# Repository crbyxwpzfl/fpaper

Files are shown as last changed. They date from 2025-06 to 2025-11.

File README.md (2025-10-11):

#### https://github.com/Elecrow-RD/CrowPanel-ESP32-4.2-E-paper-HMI-Display-with-400-300 - original files/docs
#### https://github.com/javl/image2cpp - the dithering is so cool javl
#### https://www.autodesk.com/community/gallery/project/132949/sg90-9g-micro-servo - nice servo modell of ccirone2
#### rest - is ai and me

todo - advanced perhpas stupid - store pointers to responsive peers in a vector of pointers to peer structs. on start up load complete peers blob into second allpeers vector with actual contigous structs holding the data. then on first connection put pointers to responsive peers into this first vector. then once one peer goes offline or comes back just update the pointer vector. for recieving a message this reduces the amount of hkdfs to try and no check for offline bool would be neccessary. but this uses uint32 pointer instead of just bool perhps this overhead is ok perhapsthis is even better than haveing the bool in a struct since alingmnet and wasted bufferbytes. 

todo - test thread safety thoroughly esp. revise onTopic callback

todo - curretnly 200KB ram is free this is not too much consider moving stuff to PSRAM

todo - perhpas reduce app partion to 1MB and increase nvs space to 4MB to allow more foto space

todo - add ram info and revise prefernces like rotation,btn pin, add show anything cmd,

todo - silence epd and mqtt lib

todo - revise boot sequence first sohw boot screen perhaps even progressbar (partial refresshs) also only start mqtt task when wifi connected ans so on

vision - do not hardcode firmware link istead querry latest release and compare to current version

vision - this perhaps is stoopid but somehow encrypt hkdfs until used so a leak/dump is not catastrophic

vision - replace prefs. reads and puts with perhpas rtos message buffers for thread safety

vision - forward secrecy and somthing like diffi hellman/newhope/kyber

vision - use encryption of nvs

vision - auto recover from connection loss

this is the current custom partition no spiffs!! also always set app0 at 0x10000 otherwise merged.bin is broken
```
| Name     | Type  | SubType  | Offset   | Size     | Size (MB)   |
|----------|-------|----------|----------|----------|-------------|
| otadata  | data  | ota      | 0x9000   | 0x2000   | 0.00781 MB  |
| app0     | app   | ota_0    | 0x10000  | 0x200000 | 2.00000 MB  |
| app1     | app   | ota_1    | 0x210000 | 0x200000 | 2.00000 MB  |
| coredump | data  | coredump | 0x410000 | 0x10000  | 0.06250 MB  |
| nvs      | data  | nvs      | 0x420000 | 0x200000 | 2.00000 MB  |

-- total ~6.07/8 MB (~1.93 MB free)
```

previously we had minispiffs
```
Label       Offset     Size (hex)   Size (bytes)    Size (KB)   Size (MB)
nvs         0x009000   0x005000     20,480          20.0        0.0195
otadata     0x00E000   0x002000     8,192           8.0	        0.0078
app0        0x010000   0x1E0000     1,966,080       1,920.0     1.875
app1        0x1F0000   0x1E0000     1,966,080       1,920.0     1.875
spiffs      0x3D0000   0x020000     131,072         128.0       0.125
coredump    0x3F0000   0x010000     65,536          64.0        0.0625

Region          Start       End         Size (bytes)    Size (MB)
Bootloader      0x0000      0x8000      32,768          0.03125
Partition Table 0x8000      0x9000      4,096           0.0039
All partitions  0x9000      0x400000    4,142,848       ~3.95
Unused          0x400000    0x800000    4,194,304       4.0
```

install arduino cli
```
curl -fsSL https://raw.githubusercontent.com/arduino/arduino-cli/master/install.sh | BINDIR=/home/codespace/.local/bin sh
```

allow lib form git links
```
export ARDUINO_LIBRARY_ENABLE_UNSAFE_INSTALL=true
```

init arduino sketch
```
arduino-cli sketch new "test"
```

update core index
```
arduino-cli core update-index  --additional-urls "https://espressif.github.io/arduino-esp32/package_esp32_index.json"
```

find core paltform
```
arduino-cli board search esp32
```

install core platform 
```
arduino-cli core install esp32:esp32
```

find board fqbn
```
arduino-cli board search ESP32S3 Dev Module
```

check board
```
arduino-cli board details -b esp32:esp32:esp32s3:PartitionScheme=custom,PSRAM=opi,FlashMode=qio,FlashSize=8M
```

compile with
```
arduino-cli compile -v --fqbn esp32:esp32:esp32s3:PartitionScheme=custom,PSRAM=opi,FlashMode=qio,FlashSize=8M --build-path ./firmware
```

/home/codespace/.arduino15/packages/esp32/hardware/esp32/3.2.0/tools/partitions

arduino-cli compile -v --fqbn esp32:esp32:esp32s3:PartitionScheme=custom,CustomPartitions=partitions,PSRAM=opi,FlashMode=qio,FlashSize=8M --build-path ./firmware

cp /workspaces/fpaper/test/partitions.csv /home/codespace/.arduino15/packages/esp32/hardware/esp32/3.2.0/tools/partitions/custom.csv

'merged.bin' at adress 0x0 with https://espressif.github.io/esptool-js/ for web programming

/home/codespace/.arduino15/packages/esp32/tools/esptool_py/4.9.dev3/esptool --chip esp32s3 partition_table --partition-table-file partitions.csv

esptool.py --chip esp32s3 merge_bin -o merged.bin --flash_mode qio --flash_freq 80m --flash_size 8MB \
  0x0 firmware/test.ino.bootloader.bin \
  0x8000 firmware/test.ino.partitions.bin \
  0x9000 nvs_data.bin \
  0x210000 firmware/test.ino.bin

/home/codespace/.arduino15/packages/esp32/tools/esptool_py/4.9.dev3/esptool --chip esp32s3 merge_bin -o merged-manual.bin --flash_mode qio --flash_freq 80m --flash_size 8MB \
  0x0 firmware/test.ino.bootloader.bin \
  0x8000 firmware/test.ino.partitions.bin \
  0x210000 firmware/test.ino.bin

psram view - 
```
void setup() {
  Serial.begin(115200);

  if (psramFound()) {
    Serial.println("PSRAM is found!");

    Serial.print("Total PSRAM: ");
    Serial.println(ESP.getPsramSize());

    Serial.print("Free PSRAM: ");
    Serial.println(ESP.getFreePsram());
  } else {
    Serial.println("No PSRAM available.");
  }
}
```

ram view - 
```
void setup() {
  Serial.begin(115200);
  
  // Total heap available
  Serial.print("Total heap: ");
  Serial.println(ESP.getHeapSize());

  // Free heap
  Serial.print("Free heap: ");
  Serial.println(ESP.getFreeHeap());

  // Minimum ever free heap (worst case)
  Serial.print("Minimum free heap: ");
  Serial.println(ESP.getMinFreeHeap());

  // Largest contiguous block that can be allocated (optional)
  Serial.print("Max allocatable block: ");
  Serial.println(heap_caps_get_largest_free_block(MALLOC_CAP_8BIT));
}
```

esp webrtc anywhere -https://www.reddit.com/r/esp32/comments/atnl6r/esp32_anywhere_access_webrtc_stun_turn_ice/

public mwtt broker - https://www.emqx.com/en/blog/popular-online-public-mqtt-brokers
emqx seems yo silently drop large messages hive does not

esp webrtc plus bootstrap - https://www.hackster.io/donowak/esp32-web-server-using-bootstrap-4-and-websockets-0bf950

esp webrtc stream - https://github.com/sepfy/libpeer/tree/main/examples/esp32

esp husarnet tailnetlike - https://medium.com/husarion-blog/lan-network-for-microcontrollers-over-the-internet-fbcfe4c97f4b

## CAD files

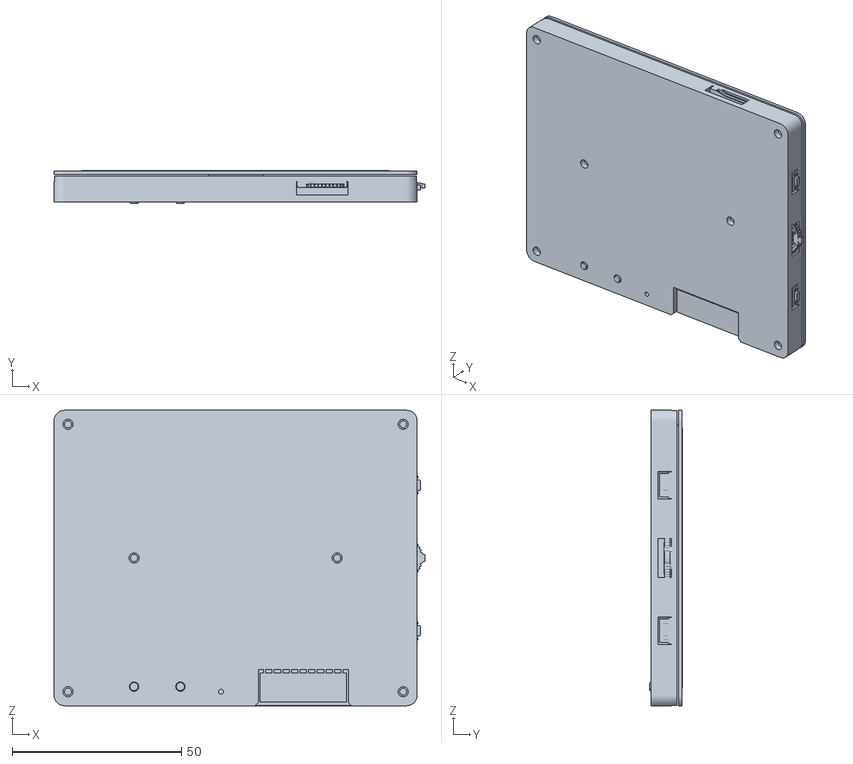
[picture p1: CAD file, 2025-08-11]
fusion files/original full assembly.stl
109.6 x 9.80 x 87.3

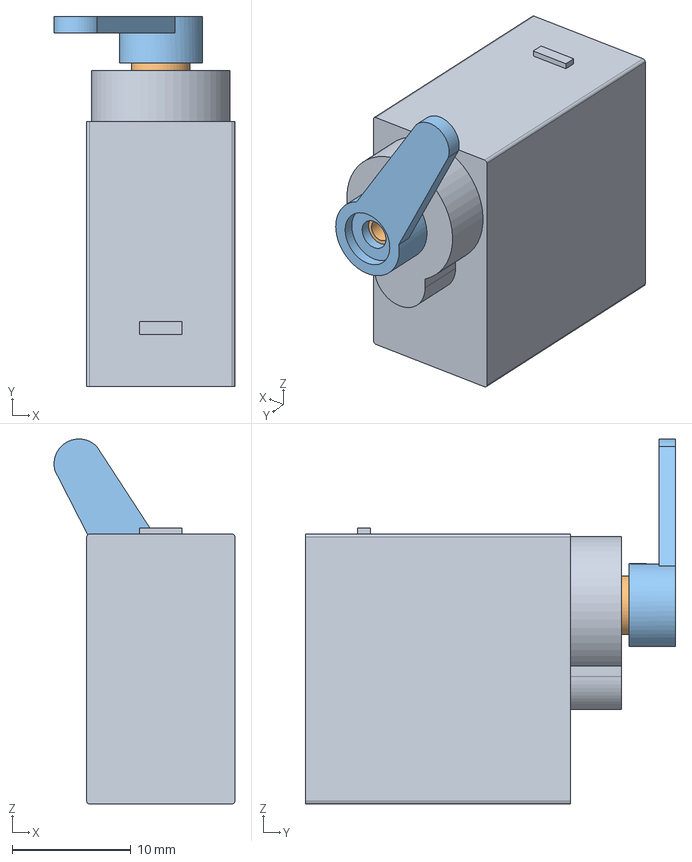
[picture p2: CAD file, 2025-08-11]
fusion files/fp servo v4.step
15.3 x 31.2 x 30.8 mm
servo_1
splined-drive
horn

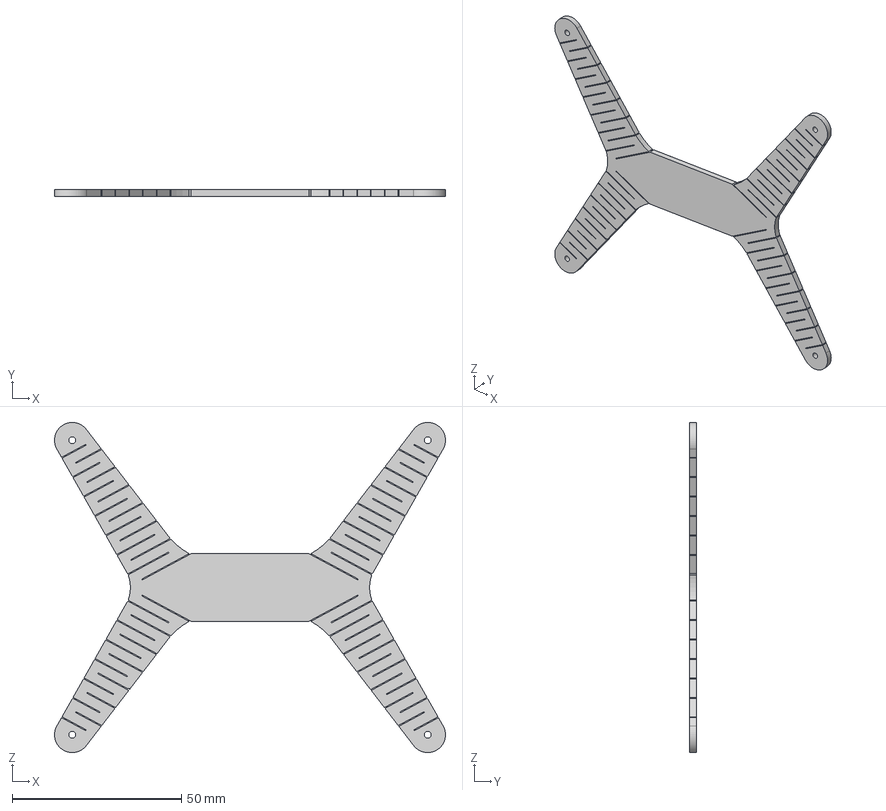
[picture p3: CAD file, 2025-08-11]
fusion files/fp flexplate v15.step
115.5 x 2.00 x 97.5 mm
Komponente1
Komponente7

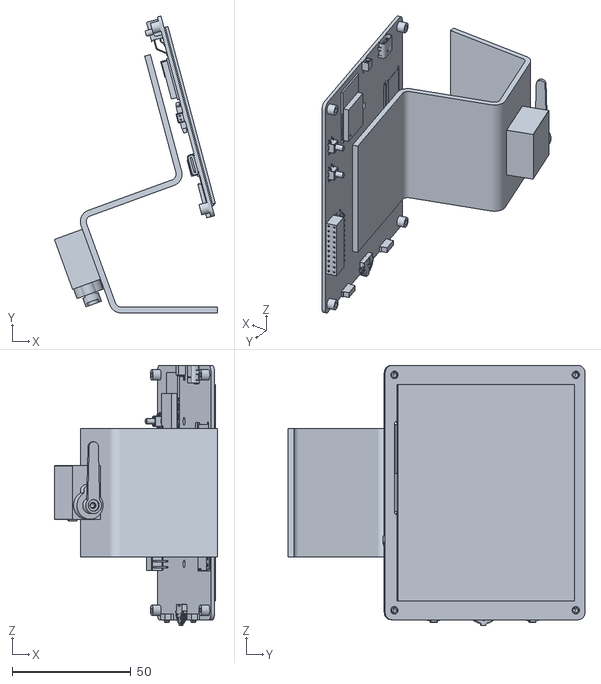
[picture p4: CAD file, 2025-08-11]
fusion files/fp mac like v2.stl
68.7 x 124.9 x 109.4

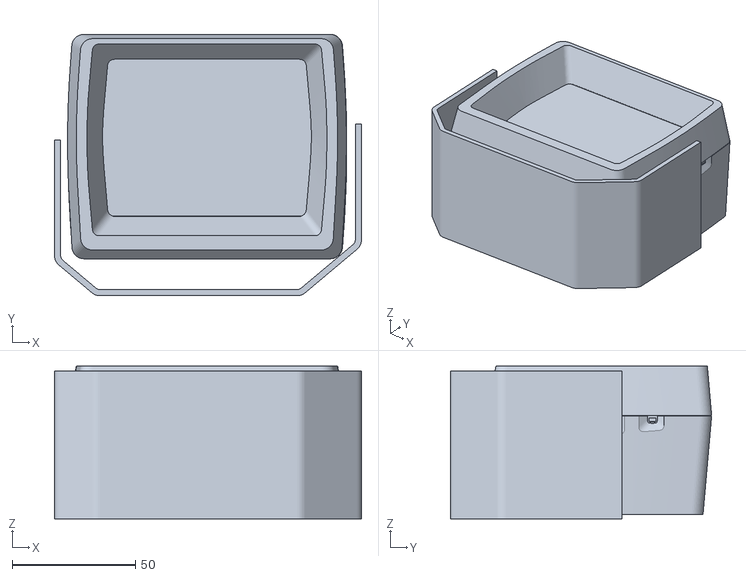
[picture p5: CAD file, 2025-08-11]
fusion files/fp severence v4.stl
124.5 x 105.9 x 62.0

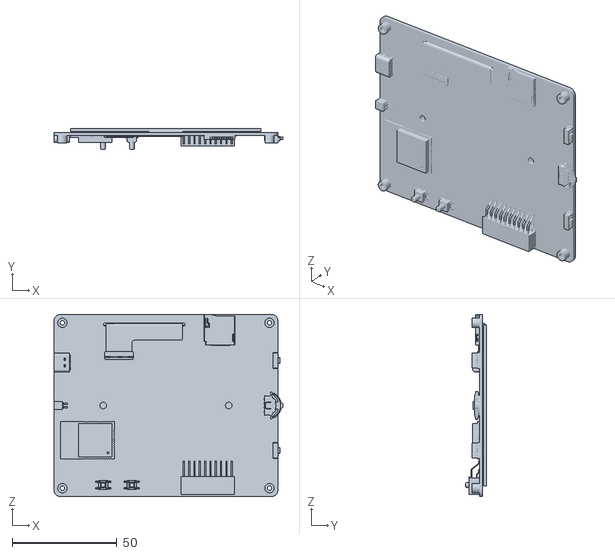
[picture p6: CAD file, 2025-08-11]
fusion files/original panel + pcb.stl
109.4 x 9.80 x 87.0

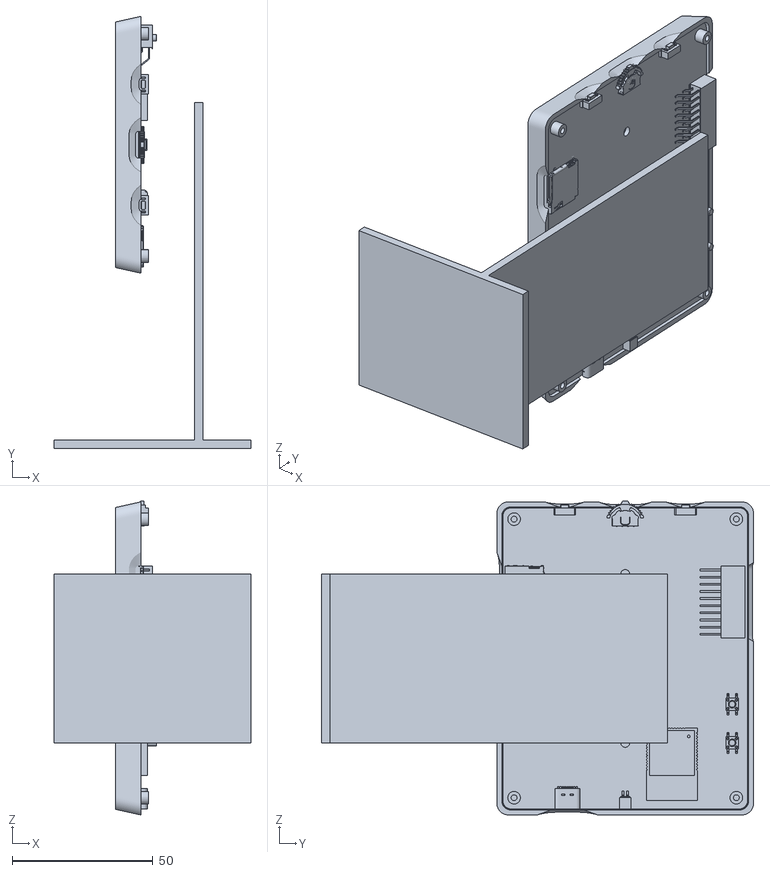
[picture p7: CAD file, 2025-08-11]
fusion files/fp simplestand v13.stl
70.0 x 153.7 x 111.6

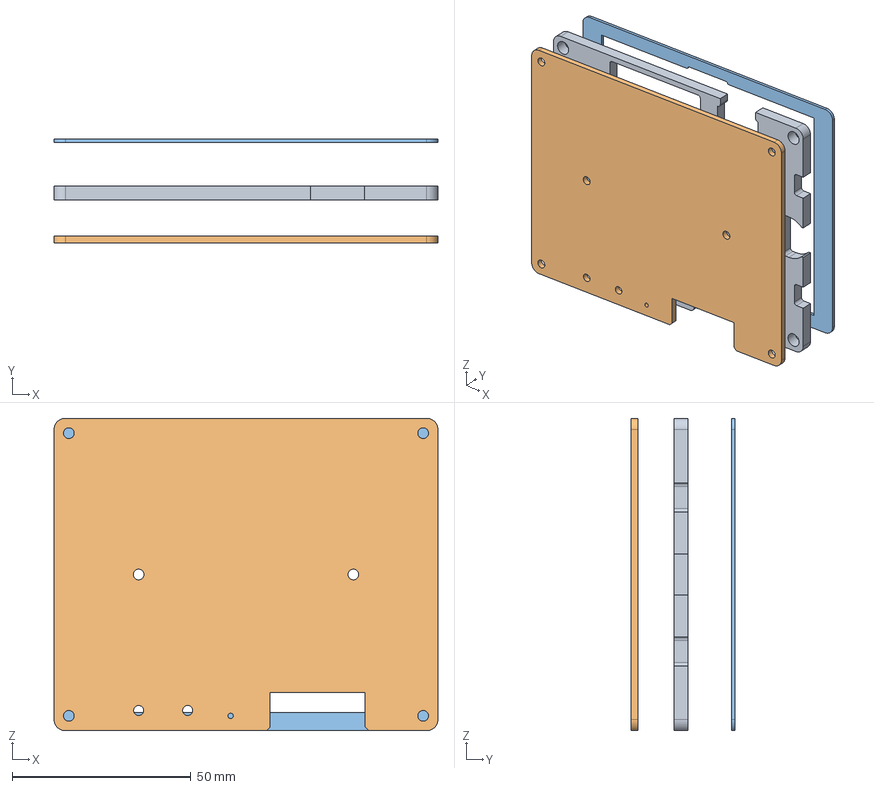
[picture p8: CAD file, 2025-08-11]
fusion files/original plates.step
107.3 x 29.1 x 87.3 mm
42-MIDDLE-COVER
42-BOTTOM-COVER
42-TOP_COVER

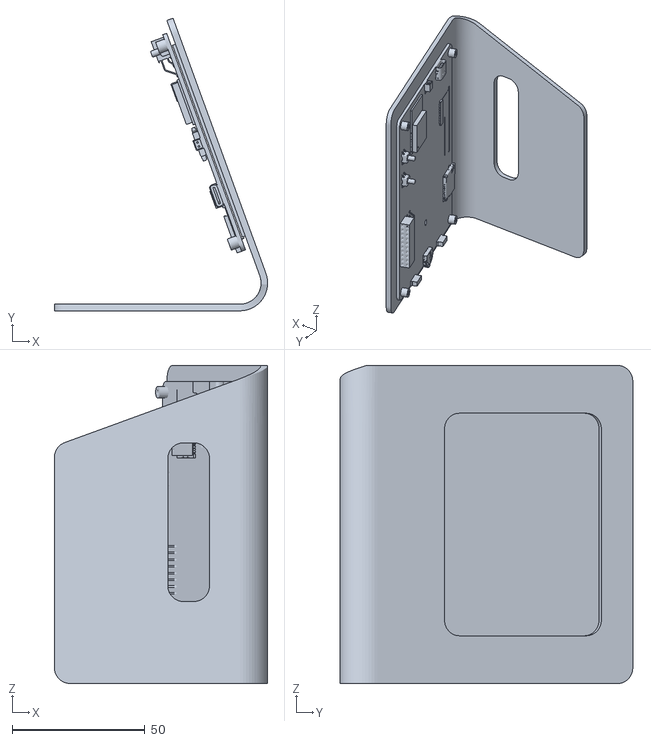
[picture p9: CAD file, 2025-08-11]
fusion files/fp raw frame v7.stl
80.5 x 110.4 x 120.0

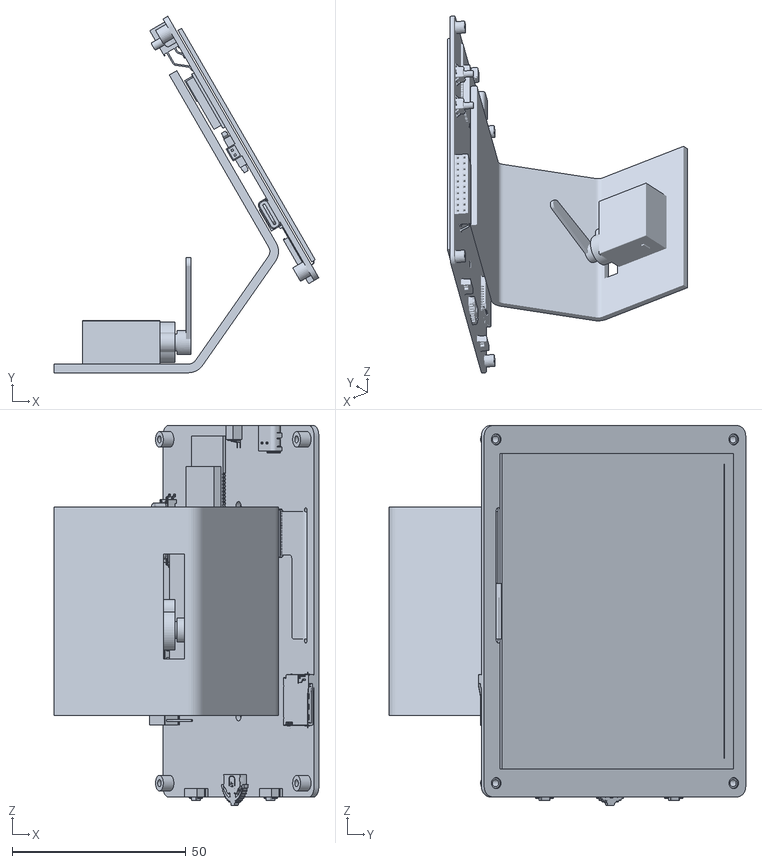
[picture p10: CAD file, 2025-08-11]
fusion files/fp cash register v2.stl
76.2 x 102.7 x 109.4

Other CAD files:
fusion files/fp cash register v2.f3z
fusion files/fp flexplate v15.f3z
fusion files/fp flexplate v15.stl
fusion files/fp mac like v2.f3z
fusion files/fp raw frame v7.f3z
fusion files/fp servo v4.f3d
fusion files/fp servo v4.stl
fusion files/fp severence v4.f3z
fusion files/original plates.stl

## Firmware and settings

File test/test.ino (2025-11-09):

//  switched to arduinocli since platformio does not really support arduino core v3 eventually I really want to switch to idf and ditch arduino in the long term
//  `arduino-cli sketch new all-together-arduino`    init sketch
//  'arduino-cli core update-index'    fetches latest core index
//  'arduino-cli board search Adafruit Feather esp32s3'    find board
//  'arduino-cli core install esp32:esp32'    install matching core see Platform ID
//  'arduino-cli lib install -v --git-url 'url' '    install library from git set environment variable 'export ARDUINO_LIBRARY_ENABLE_UNSAFE_INSTALL=true' use verbos to find liberary dir for edits
//  'arduino-cli compile -v --fqbn esp32:esp32:adafruit_feather_esp32s3 --build-path ./firmware -upload -p /dev/tty.usbmodem101 '    compile for fqbn form board search esp32:esp32:adafruit_feather_esp32s3 also puts binaries into firmware folder
//  use 'merged.bin' at adress 0x0 with https://espressif.github.io/esptool-js/ for web programming



//#include <Arduino.h>    // all this is arduino for an esp32    so compared to c some delacrations are missing but im not sure 
#include <Preferences.h>
#include <HTTPClient.h>
#include <WiFiClientSecure.h>
#include <Update.h>
#include <HTTPUpdate.h>
#include <ESPmDNS.h>
#include <DNSServer.h>
#include <WiFi.h>

#include <AsyncTCP.h>    //  https://github.com/mathieucarbou/AsyncTCP.git MOVED to https://github.com/ESP32Async/AsyncTCP.git
#include <ESPAsyncWebServer.h>     //  https://github.com/mathieucarbou/ESPAsyncWebServer.git  MOVED to https://github.com/ESP32Async/ESPAsyncWebServer.git
#include <MycilaWebSerial.h>  // https://github.com/mathieucarbou/MycilaWebSerial.git customize portal 'cd library/dirs/MycilaWebSerial/portal/' customize html delete 'library/dirs/MycilaWebSerial/src/MycilaWebSerialPage.h' regenerate it 'pnpm i' 'pnpm build' node and pnpm is required
#include "InterruptButton.h"    //  https://github.com/rwmingis/InterruptButton.git
#include <PsychicMqttClient.h>    //  https://github.com/theelims/PsychicMqttClient.git


#include <ChaChaPoly.h>    // https://github.com/rweather/arduinolibs.git
#include <SHA256.h>
#include <HKDF.h>


#include <GxEPD2_BW.h>  //  https://github.com/ZinggJM/GxEPD2.git + https://github.com/adafruit/Adafruit-GFX-Library.git + https://github.com/adafruit/Adafruit_BusIO.git for epaper GDEY042T81 4.2" b/w 400x300, SSD1683 on elecorw CrowPanel ESP32 E-Paper HMI 4.2-inch Display
#include <xpwallpaper.h>  //  test image bitmap

#include <cstdarg>
#include <cstdio>

#include <unordered_map>    //  c++ stuff
#include <functional>
#include <string>


// ----------- TODO -----------
//
//  currently app uses ~1,4MB of flash perhaps reduce this to less than 1MB
//  currently 180KB internal Ram is remaining this is not too much
//
//  major restructuring concerns
//  - correct startup sequence eg wifi has to start first only then webserial and mqtt task can start
//
//  sartup order
//  - all tasks would like to send logs class has to be inited first
//  - network task is required for webserial and mqtt
//
// prpper boot screen would be nice eg. with  while (WiFi.status() != WL_CONNECTED) {delay(500); Serial.print("."); } and similar
//
// set a strong unique client id for mqtt to ensure broker wider unique id ids are not topic scoped!
// - mqttClient.setClientId(const char *clientId); // has to be <23bytes UTF-8 encoded string for MQTT 3.1.1 defaults to last 3 bytes of the MAC address in hex format
// - esp32s3 has only 6 bytes MAC see https://github.com/espressif/esp-idf/blob/800f141f94c0f880c162de476512e183df671307/components/efuse/esp32s3/esp_efuse_table.c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
// - what happens on session hijacking? is a last will message sent? will i just reconnect with same id and potentially fight indefinitely with hijacker?
//
// add ciritcal screen for very bad errors that require user intervention like dos detected, replay detected and so on ....
//
// migrate to peer struct instead of standalone vectors
// 
// make the .ontopic callback more threadsafe
// - theoretacally multible callbacks can run at the same time and esp. change index so either add this last success index to nvs class as a cached value or do not use it at all
// - while a decrypt is in progress do not allow peer struct to be changed eg. deleting a peer, adding a peer
// - perhaps also take the nvs mutex while decrypting to avoid changes to peers but this would only allow one decrypt process at a time but likely this already is the case
// - perhaps make snapshot/copy of peers vector under lock and the use this to decrypting
//
//
// ------------ obvious vulnerabilities ------------
//
// - (1.) replay/dos by publishing profilehashes wich then cause peers to register the true owner of this profilehash as offline
//   this is so cheap and is so impactful this has to be fixed
//   - perhaps add on receive of ownprofilehash in cleartext do full disconnect/reconnect cycle to reassert online status but this than allowes for dos amplification
//   - perhaps add on receive of ownprofilehash in cleartext show warning screen and do nothing else and let user manually reconnect
//   - perhaps allow manual granular reconnect via webserial command
//   -> some what solved - last will is randomly generated on connect and never shared unecrypted - still a bad peer could put you offline since last will can not be unique to one peer
//
// - 2. dos by flooding topic with garbage
//   perhaps add a rate limit on processing messages and throw dos warning on screen
//   drop messages of wrong size without processing
//
// - 3. replay old messages are not detected and are just accepted
//   add timestamp to messages and drop old messages
//   add little ring buffer to hold last few ivs and ignore these
//
// - 4. session hijack/takeover potentially suppresses last will message of true session owner or dublicates last will message when hijacker disconnects
//   causes other peers to send messages to a peer who is offline uneccessary traffic
//   this is not easy to fix and relies on mqtt broker configuration
//   best mitigation is to use a strong unique client id see above
//
// - 5. structured traffic reveals private info
//   message followed by lots of messages -> this likely is a pulic message, someone goes online, followups count reveals friend count
//   short to long message as followups -> reveals something about activeness of peers
//   long message and no following message -> could be a foto (private message) or a profile change (public message)
//   perhaps one can infere important members or even map out a relationship graph of the network
//   buffer all messages to same length can help a bit but causes lots of traffic especially on connect
//
// ------------- THIS SEEMS TO BE A WORKABLE SOLUTION -------------
//
//  TODO MAKE THIS A MERMAID DIAGRAMM !!!! 
//
// various message structurs 
//  - full profile message     -> (profilehash) +  lastwill  + profile
//  - short profile message    -> (profilehash) +  lastwill  +   /
//  - foto message             -> (profilehash) + (lastwill) + foto
//  - lastwill message         ->        /      +  lastwill  +   /
// (profilehash not stritly necessary but appending this relieves on message callback form also hashing profiles befor check)
// (including profile hash in every message allowes for detecting protocoll errors or violations)
//
// messages encryption convetion
//  - private messages -> encrypted with private secret -> only me and one peer knows this -> this is to send a foto to one peer
//  - public messages -> encrypted with prublic secret -> every peer knows this -> this is for messages to every peer eg profile changes or going offline
//
// flags
//  - woosh -> this peer missed a profile change
//  - offline -> well this peer is offline
//  - online -> well this peer is online
//
// protocoll erros
//  - profile error -> a recieved profile hash did not match with stored profile -> catch by asking this peer for his profile
//  - lastwill error -> a recieved lastwill did not match with stored lastwill -> gracefully overwrite lastwill
//
//
// on connect
//  -> generate random last will and register this as last will
//  -> if any woosh flag -> ping all peers via full profile message publicly (online peers will answer with full or short profile message depending on wether you was wooshed)
//  -> if no woosh flag -> ping all peers via short profile message publicly  (online peers will answer with full or short profile message depending on wether you was wooshed)
//
// on profile change
//  -> compute hash with sha2 256 https://github.com/espressif/arduino-esp32/blob/master/libraries/Hash/examples/SHA2/SHA2.ino of new profile
//  -> publish this with a full profile message publicly
//  -> remember the offline peers who missed this by setting the woosh flags of these peers
// 
// on ungracefull disconnect alias last will
//  -> server sends last will message to all online peers
//
// on recieve of known lastwill message (determinated via length)
//  -> mark this peer as offline if found
//
// on peer add
//  -> send full profile message encrypted with new peers secret just to one peer
//
// on recieve plus successfull decrypt
//  -> for a ping (a public message) (full or short profile message)
//     - if sender offline and sender wooshed -> answer with full profile message privately  (sender missed a profile change and tell him you are online)
//     - if sender offline and sender not wooshed -> anser with short profile message privately  (sender already has current profile just tell him you are online)
//     - if sender online then this is a profile change -> do not answer  (you already answered to ping befor otherwise sender would not be online so just accept the profile change)
//     - if full profile message -> potentially overwrite profile of sender, update profilehash of sender
//     - if short profile message -> confirm profilehash or raise protocoll profile error, on error send short profile message privatly
//     - if sender online -> confirm lastwill or raise protocoll lastwill error, catch gracefully and overwrite lastwill
//     - if sender offline -> remember lastwill of sender
//     - set sender to online
//  -> for a ping response or sync to catch error (a private message) (full or short profile message)
//     - if full profile message and sender offline -> do not answer, potentially overwrite profile of sender, update profilehash of sender
//     - if short profile message and sender online -> answer with full profile message privatly
//     - if short profile message -> confirm profilehash or raise protocoll profile error, on error send short profile message privatly
//     - remember lastwill of sender
//     - set sender to online
//  -> for a latest foto (a private message) (foto message)
//     - do not answer
//     - confirm profilehash or raise protocoll profile error, on error send short profile message privatly
//     - confirm lastwill or raise protocoll lastwill error, catch gracefully and overwrite lastwill
//     - show foto
//  -> for a sync message
//     -  send full profile message privatly
//
//
// issues
//  - messages have different length this leaks info about what is sent
//    foto and full profile message or short profile messages can be differentiated
//    this leaks wehere a handshake happens (someone pings) and where actual data is sent
//  - perhaps makes public who knows how many peers
//  - lots of messages on connect
//  - tracks online status of peers
//  - rlies on broker implementation of lastwill
//
// pros
//  - messages have different length this minimizes traffic
//  - dont send unnecessary messages after initial sync
//  - tracks online status of peers relieves network preassure
//
// ------------------------------------------------------------------
//
//
//
//
//

//  ---------- key insights while testing ----------
//
// - swithcing to     // if( xQueueReceive( comms::mqsendq, &send, 0 ) == pdPASS ) { ... } xTaskYIELD();
//   for all tasks makes the programm run in a very tight loop and starves the idle task so the watchdog is not reset and triggers
//   before the xTaskDelay(1) would allow the idle task to run
//   so for everytask without a queue use xTaskDelay(1) instead of taskYIELD() to allow idle task to run and reset watchdog
//
// - if( xQueueReceive( comms::mqsendq, &send, portMAX_DELAY ) == pdPASS ) { ... } does not block the cpu but just moves the task to waiting state until sth is in the queue
//   this is exactly what is wanted
//
// - xTaskCreate does, even with arduino, not place all tasks on core1 so use xTaskCreatePinnedToCore to ensure this
//   otherwiese make sure that all recources are thread safe e.g. nvs access use semaphores or mutexes
//   this RAII nvs::prefslock is very cool and so nice to use
//
// - MDNS is broken somehow!!
//
//


class comms {    //  this is for all the inter task communication via queues    essentially these are globals not sure this namespace thing is good practice
  public:
  inline static QueueHandle_t showq = nullptr;    //  provide public access to the queue handles instead of private and access functions
  inline static QueueHandle_t mqsendq = nullptr;    // c++17 inline variable avoids static member definition at global scope
  inline static QueueHandle_t servoq = nullptr;

  struct showstct { char ocupado[5]; uint8_t partial; char nvsalias[16]; };   //  make struct public so it can be used outside of class    this hard coded finite length stresses me in python me no have to worry me miss python
  struct mqsendstct { uint32_t peer; char load[16]; };
  struct servostct { char pos[4]; };    //  no struct required for servo queue

  static void init() {    //  no constructor instead have treat theses as global utils    also feels not so racey
    if (showq == nullptr) showq = xQueueCreate(5, sizeof(showstct));
    if (mqsendq == nullptr) mqsendq = xQueueCreate(5, sizeof(mqsendstct));
    if (servoq == nullptr) servoq = xQueueCreate(5, sizeof(servostct));
  }

  static bool toshowq(const char* ocupado, uint8_t partial, const char* format, ...) {
    if (!showq) return false;
    
    showstct show{};
    strncpy(show.ocupado, ocupado ? ocupado : "", sizeof(show.ocupado) - 1);
    show.partial = partial;

    va_list args;    //  this is basicly a snprintf into the struct member
    va_start(args, format);
    vsnprintf(show.nvsalias, sizeof(show.nvsalias), format, args);
    va_end(args);

    return xQueueSend(showq, &show, 0) == pdPASS;
  }

  static bool tomqsendq(uint32_t peer, const char* format, ...) {
    if (!mqsendq) return false;
    
    mqsendstct send{};
    send.peer = peer;

    va_list args;    //  this is basicly a snprintf into the struct member
    va_start(args, format);
    vsnprintf(send.load, sizeof(send.load), format, args);
    va_end(args);

    return xQueueSend(mqsendq, &send, 0) == pdPASS;
  }

  static bool toservoq(const char* pos) {
    if (!servoq) return false;
    servostct servo{};
    strncpy(servo.pos, pos ? pos : "", sizeof(servo.pos) - 1);
    return xQueueSend(servoq, &servo, 0) == pdPASS;
  }
};
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
void loop() {vTaskSuspend(NULL);}    //  all done in tasks so suspend loop    todo is it possible to do vTaskDelete(NULL) here

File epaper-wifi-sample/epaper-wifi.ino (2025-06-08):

#include <Arduino.h>           // Include the Arduino core library

#include "EPD.h"               // Include the EPD library for controlling the electronic ink screen (E-Paper Display)
#include "EPD_GUI.h"           // Include the EPD_GUI library for graphical user interface (GUI) operations
#include "Ap_29demo.h"         // Include the Ap_29demo library, which may be a custom application library
#include <WiFi.h>              // Include the WiFi library for Wi-Fi functionality
#include <Ticker.h>            // Include the Ticker library for timer tasks
#include <WebServer.h>         // Include the WebServer library for creating a web server
#include "FS.h"                // Include the file system library for file operations
#include "SPIFFS.h"            // Include the SPIFFS library for the SPIFFS file system

// Define an array to store image data, with a size of 15000 bytes
uint8_t ImageBW[15000];

// Define the sizes of txt and pre image data
#define txt_size 3808
#define pre_size 4576






// Clear all content on the display
void clear_all()
{
  EPD_Clear(); // Clear the display content
  Paint_NewImage(ImageBW, EPD_W, EPD_H, 0, WHITE); // Create a new image buffer, filled with white
  EPD_Full(WHITE); // Fill the entire screen with white
  EPD_Display_Part(0, 0, EPD_W, EPD_H, ImageBW); // Update the display content
}

// Create a WebServer instance, listening on port 80
WebServer server(80);

// Define the hotspot name
const char *AP_SSID = "ESP32_Config"; // Configure the ESP32 hotspot name

// Define the HTML form for uploading files
String HTML_UPLOAD = "<form method=\"post\" action=\"ok\" enctype=\"multipart/form-data\">\
<input type=\"file\" name=\"msg\">\
<input class=\"btn\" type=\"submit\" name=\"submit\" value=\"Submit\">\
</form>";

// Handle root directory requests, return the upload form
void handle_root()
{
  server.send(200, "text/html", HTML_UPLOAD); // Send the upload form to the client
}

// HTML page after successful upload
String HTML_OK = "<!DOCTYPE html>\
<html>\
<body>\
<h1>OK</h1>\
</body>\
</html>";

// File object for storing uploaded files
File fsUploadFile;  // File object used to store the uploaded file

// Define an array for storing uploaded image data
unsigned char test1[15000]; // Temporary array for storing image data
unsigned char price_formerly[pre_size]; // Array for storing price image data
unsigned char txt_formerly[txt_size]; // Array for storing text image data

String filename; // String to store the filename

// Flags to mark different image data
int flag_txt = 0; // Flag to mark whether text image data exists
int flag_pre = 0; // Flag to mark whether price image data exists



size_t bufOffset = 0;
void handleFileUpload() {
  HTTPUpload& upload = server.upload();
  if (upload.status == UPLOAD_FILE_START) {
    bufOffset = 0;
  } else if (upload.status == UPLOAD_FILE_WRITE) {
    // Make sure we don't overflow test1[]
    size_t copyLen = min(upload.currentSize, sizeof(test1) - bufOffset);
    memcpy(&test1[bufOffset], upload.buf, copyLen);
    bufOffset += copyLen;
  } else if (upload.status == UPLOAD_FILE_END) {
    // Now test1 contains the file data
    Serial.printf("Upload complete, %zu bytes in buffer\n", bufOffset);
    // Now you can show the picture:
    
    clear_all();
    EPD_ShowPicture(0, 0, 400, 300, test1, WHITE);
    EPD_Display_Fast(ImageBW);
    EPD_Sleep();
  }
}

// Function to handle file upload requests
void okPage()
{
  server.send(200, "text/html", HTML_OK); // Return the page indicating successful upload
  HTTPUpload &upload = server.upload(); // Get the uploaded file

  // Note: The default size of upload.buf may not be sufficient to handle large files
  // Please refer to the definition of HTTP_UPLOAD_BUFLEN in WebServer.h, adjust the initial size to support large file transfers
  if (upload.status == UPLOAD_FILE_END) // If file upload is complete
  {
    Serial.println("draw file"); // Print debug information: file upload complete
    Serial.println(upload.filename); // Print the uploaded filename
    Serial.println(upload.totalSize); // Print the size of the uploaded file
    
    /*
    if (upload.totalSize == txt_size) // Check if the uploaded file size matches the predefined txt_size
      filename = "txt.bin"; // Set the filename to txt.bin
    else
      filename = "pre.bin"; // Otherwise, set the filename to pre.bin
    if (!filename.startsWith("/")) filename = "/" + filename; // If the filename does not start with '/', add '/' prefix
    fsUploadFile = SPIFFS.open(filename, FILE_WRITE); // Open the file for writing
    fsUploadFile.write(upload.buf, upload.totalSize); // Write the uploaded file data to the file
    fsUploadFile.close(); // Close the file
    Serial.println("Saved successfully"); // Print the message that the save was successful
    Serial.printf("Saved: "); // Print the saved filename
    Serial.println(filename);
    */

    /*
    // Copy the uploaded file data to the corresponding buffer array
    if (upload.totalSize == txt_size)
    {
      for (int i = 0; i < txt_size; i++) {
        txt_formerly[i] = upload.buf[i]; // Copy data to txt_formerly
      }
      Serial.println("txt_formerly OK"); // Print the message that txt_formerly has been successfully updated
      flag_txt = 1; // Set the flag_txt to 1
    } else
    {
      for (int i = 0; i < pre_size; i++) {
        price_formerly[i] = upload.buf[i]; // Copy data to price_formerly
      }
      Serial.println(" price_formerly OK"); // Print the message that price_formerly has been successfully updated
      flag_pre = 1; // Set the flag_pre to 1
    }
    */
    //clear_all();  // Clear all content on the display

    //EPD_ShowPicture(0, 0, 400, 300, test1, BLACK);
    //EPD_Display_Fast(ImageBW);

    /*
    // Display the background image
    //EPD_ShowPicture(0, 0, EPD_W, 40, background_top, WHITE); // Display the background image on the screen, with the background color as white
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

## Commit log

2025-06-08 adaped servo movement for display wiggle
2025-06-22 this does not work only some parts are decrypted fine other parts stay noisy whythis
    [test.ino]
2025-07-27 does not work
    [partitions.csv]
2025-07-29 this is shortest viable upload handler i think this is fine
    [test.ino]
2025-08-05 fix merged.bin with custom partition moved app0 to 0x10000
    [partitions.csv]
2025-08-06 ok we start recieve handeling now
    [partitions.csv]
2025-08-07 first prototype index.html with revised logic
2025-08-11 fusion files
    [fp cash register v2.f3z, fp cash register v2.stl, fp flexplate v15.f3z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]
2025-08-26 still missing the correct image rotation but page looks good now
    [test.ino]
2025-08-29 re structuring timing stuf to the button logic and todo list
2025-08-31 maan putting the slots in the same index as the peers does not make stuff easy
2025-09-01 flank logic almost complete but also want to add dynamic foto slot count now ..... this gets out of handman
2025-09-02 why even use structs here instead of Strings man this was easy with arduino comfort
2025-09-03 so much stuff to fix still
    [test.ino]
2025-09-04 at least button stuff works now
2025-09-05 nextup make website ask about how many slots
2025-09-05 website now queries slot count
2025-09-09 some ideas to filter mqtt echos
2025-09-09 still om mqtt echo filtering
2025-09-10 very minimal echo filter via esentially slow mode
2025-09-11 finally rework network stuff and webserial
    [test.ino]
2025-09-15 replace ifelses with unordered map
    [test.ino]
2025-09-18 so many issues still
    [test.ino]
2025-09-18 ponr - deep cut fully embrace rewrite
2025-09-30 hopefully thread save this is untested
2025-10-03 this is a hard issue
    [test.ino]
2025-10-05 obvious vulnerabilities plus potential fixes
    [test.ino]
2025-10-05 lots and lots to fix
    [test.ino]
2025-10-08 perhaps store offline bool out of band
    Added todos for improving peer management and thread safety testing.
